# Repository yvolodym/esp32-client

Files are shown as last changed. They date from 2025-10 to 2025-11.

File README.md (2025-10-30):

```bash
idf.py set-target esp32-c3
idf.py build
idf.py -p /dev/ttyUSB0 flash monitor
```

ESP-NOW spezifisch:

CONFIG_ESPNOW_ENABLE=y - ESP-NOW aktiviert
CONFIG_ESPNOW_MAX_ENCRYPT_PEER_NUM=6 - Max. verschlüsselte Peers

Wichtige ESP32-C3 spezifische Einstellungen:

Ändere die server_mac Variable mit der MAC-Adresse deines Servers
Beide Geräte müssen auf Kanal 1 sein (oder ändere ESPNOW_WIFI_CHANNEL)

Single-Core (UNICORE) - C3 hat nur einen Core
RISC-V Architektur
Optimierte IRAM-Nutzung für WiFi
WPA3 Support aktiviert

Die Konfiguration ist optimiert für:

Niedrigen Stromverbrauch
Gute WiFi-Performance
ESP-NOW Kommunikation

### PINs
```
Motor Output 1: GPIO2
Motor Output 2: GPIO3
Input 1:        GPIO4
Input 2:        GPIO5
Sleep/Enable:   GPIO6
```

### URL
* https://github.com/EzerLonginus/CH340E_USB_UART
* https://community.element14.com/technologies/open-source-hardware/b/blog/posts/ch340-building-yet-another-usb-c-to-uart-adapter-board
* https://github.com/SolderedElectronics/USB-UART-CH340C-converter-board-hardware-design
* https://hci.rwth-aachen.de/lipo

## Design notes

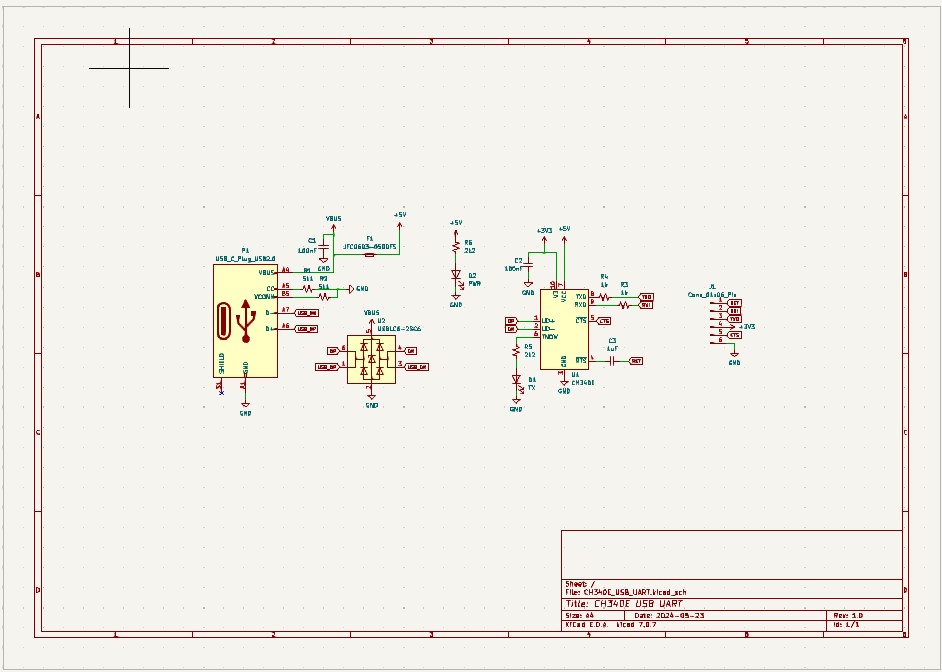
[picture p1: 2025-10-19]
doc/CH340E_schematic.jpeg

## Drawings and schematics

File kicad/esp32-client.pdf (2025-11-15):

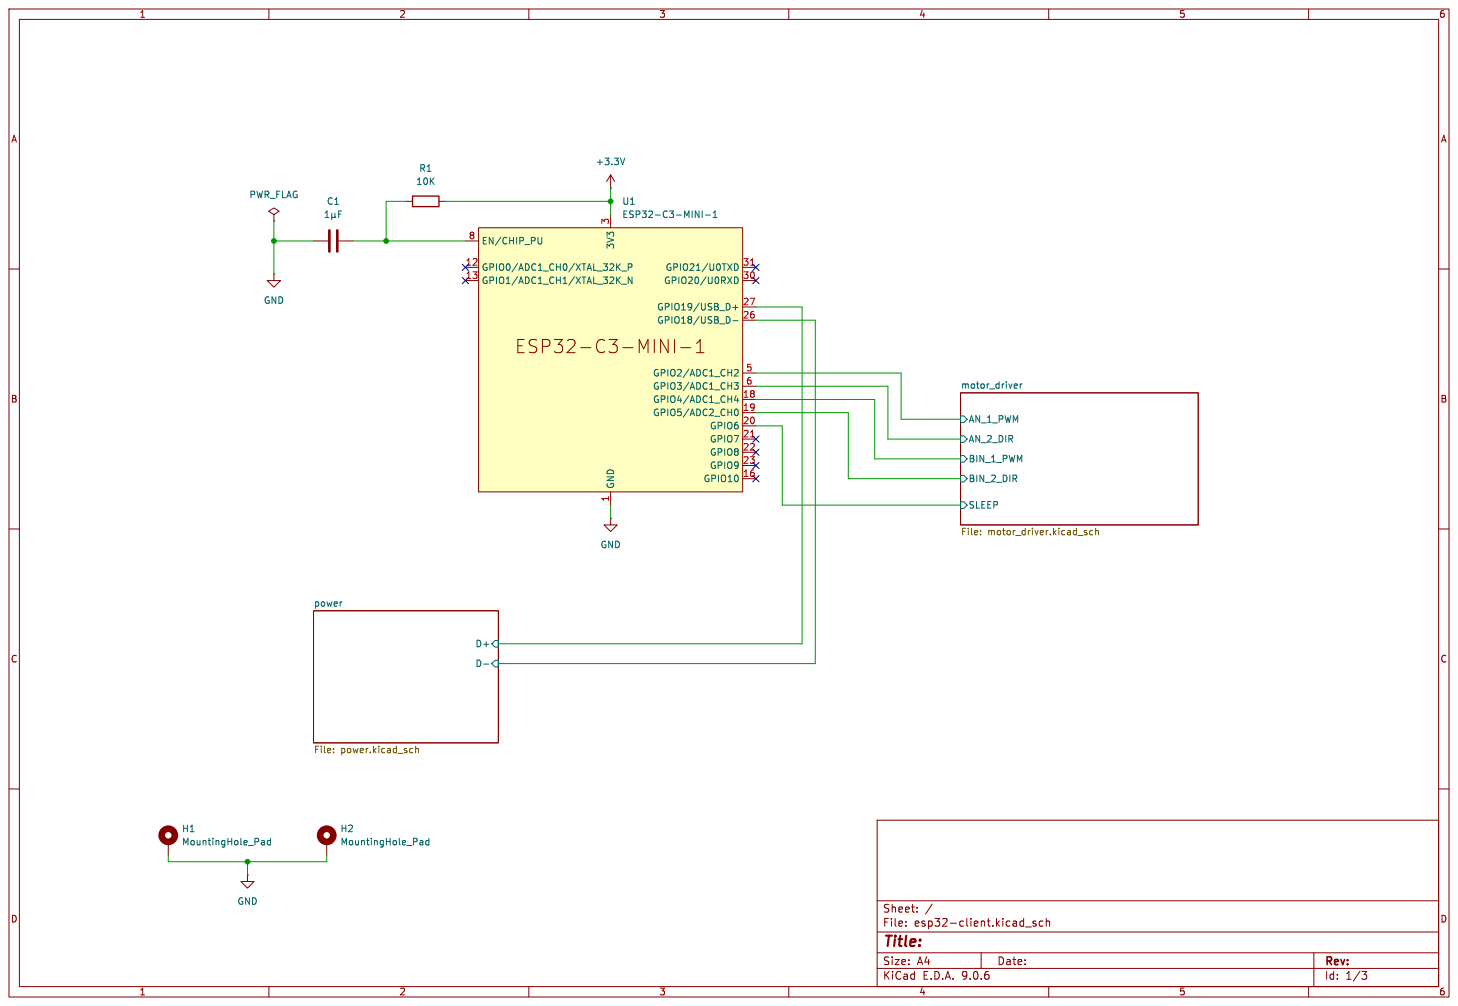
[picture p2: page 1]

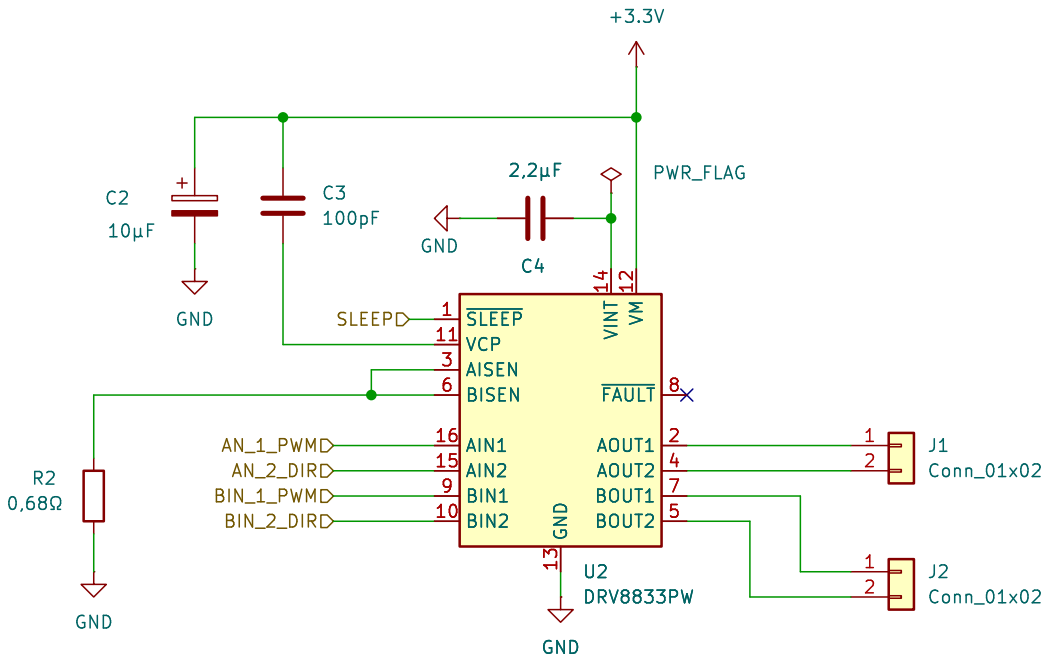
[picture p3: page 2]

Id: 2/3 Title: File: motor_driver.kicad_sch Sheet: /motor_driver/ R2

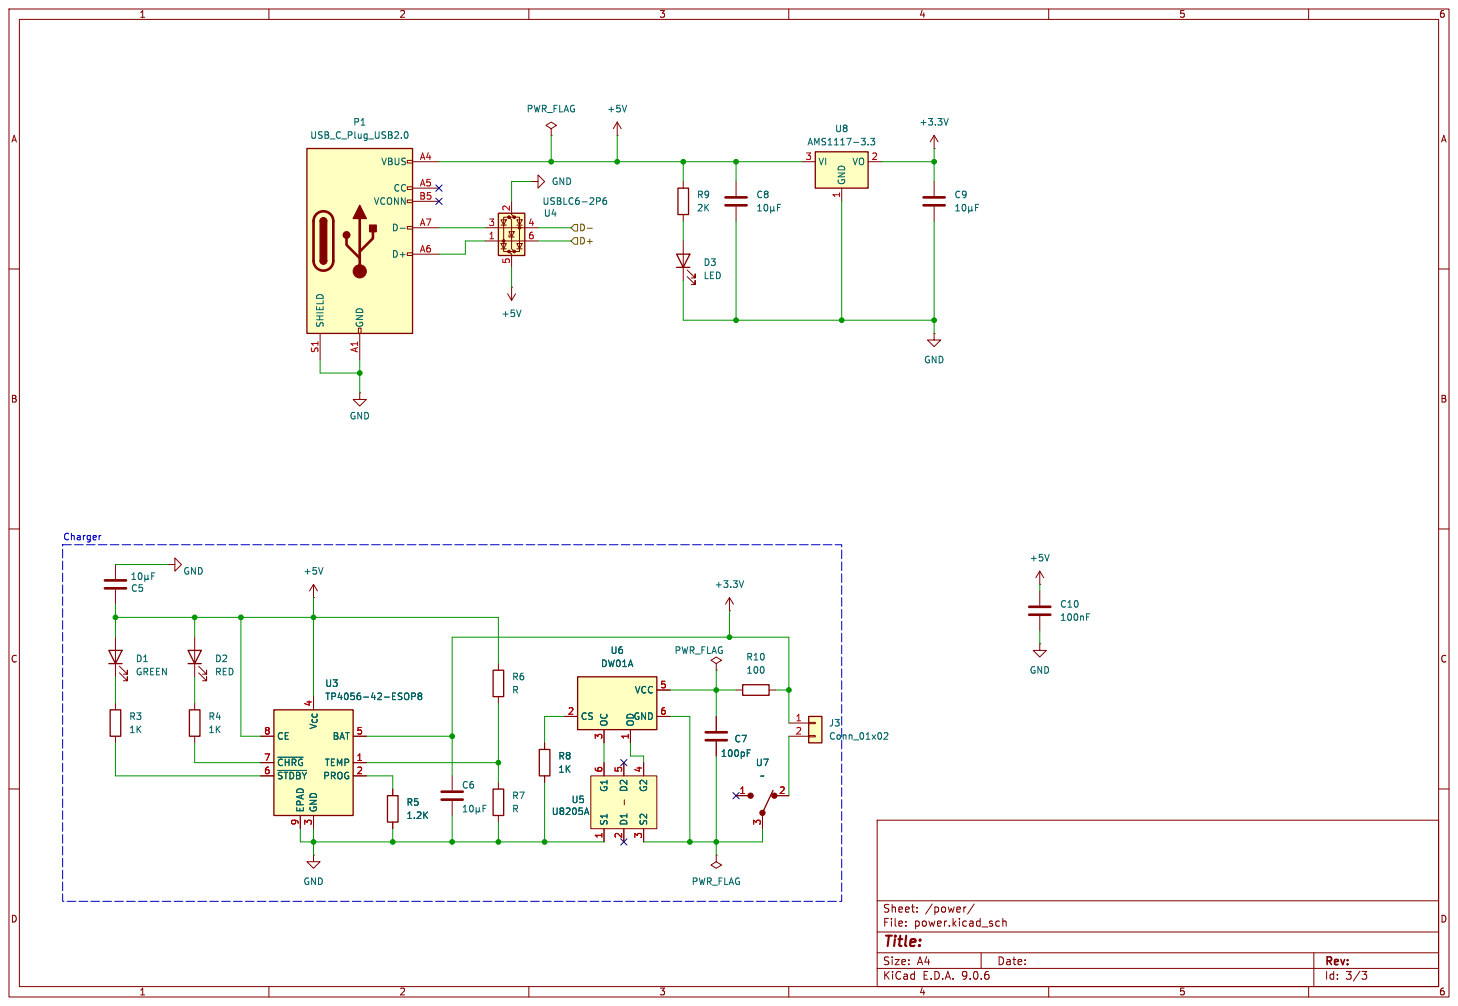
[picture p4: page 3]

3 BAT 5 TEMP 1 PROG 2 U3 TP4056-42-ESOP8 +5V GND

Id: 3/3 Title: File: power.kicad_sch Sheet: /power/ PWR_FLAG

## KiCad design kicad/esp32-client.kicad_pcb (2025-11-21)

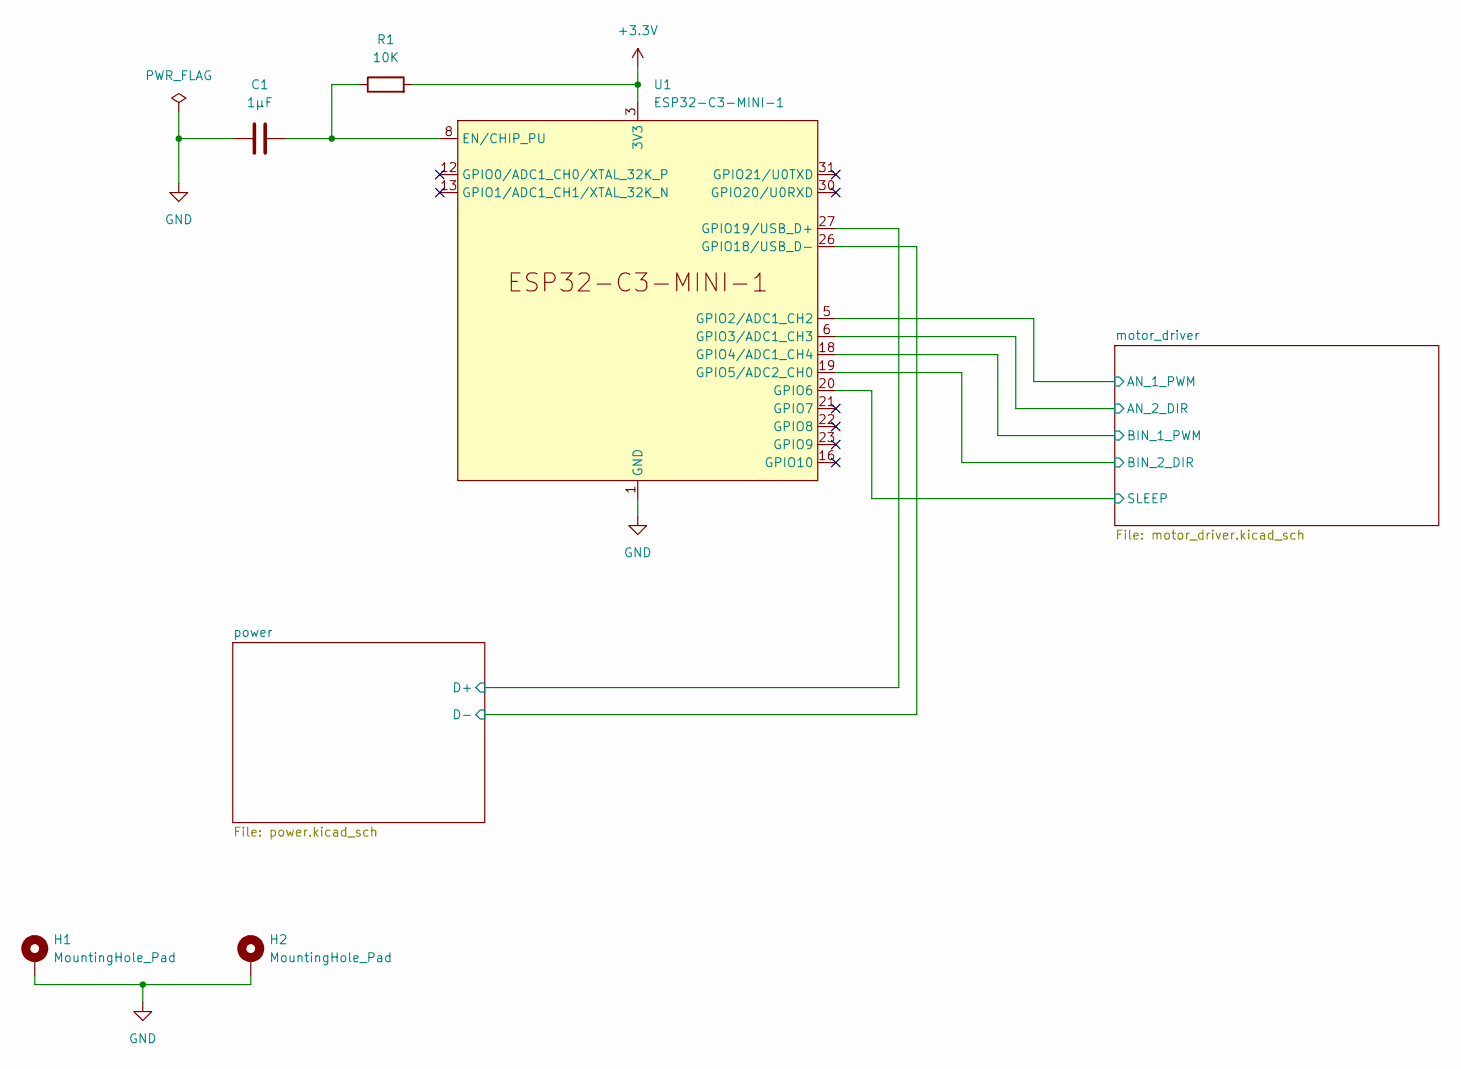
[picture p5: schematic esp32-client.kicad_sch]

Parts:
C1: 1µF; C_1206_3216Metric
H1, H2: MountingHole_Pad; MountingHole_2.5mm
R1: 10K; R_1206_3216Metric
U1: ESP32-C3-MINI-1

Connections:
+3.3V: R1.2, U1.3 (3V3); also elsewhere on the board
/motor_driver/AN_1_PWM: U1.5 (GPIO2/ADC1_CH2); also elsewhere on the board
/motor_driver/AN_2_DIR: U1.6 (GPIO3/ADC1_CH3); also elsewhere on the board
/motor_driver/BIN_1_PWM: U1.18 (GPIO4/ADC1_CH4); also elsewhere on the board
/motor_driver/BIN_2_DIR: U1.19 (GPIO5/ADC2_CH0); also elsewhere on the board
/motor_driver/SLEEP: U1.20 (GPIO6); also elsewhere on the board
/power/D+: U1.27 (GPIO19/USB_D+); also elsewhere on the board
/power/D-: U1.26 (GPIO18/USB_D-); also elsewhere on the board
GND: C1.2, H1.1, H2.1, U1.1 (GND), U1.2 (GND), U1.11 (GND), U1.14 (GND), U1.36 (GND), U1.37 (GND), U1.38 (GND), U1.39 (GND), U1.40 (GND), U1.41 (GND), U1.42 (GND), U1.43 (GND), U1.44 (GND), U1.45 (GND), U1.46 (GND), U1.47 (GND), U1.48 (GND), U1.49 (GND), U1.50 (GND), U1.51 (GND), U1.52 (GND), U1.53 (GND); also elsewhere on the board
unnamed: C1.1, R1.1, U1.8 (EN/CHIP_PU)

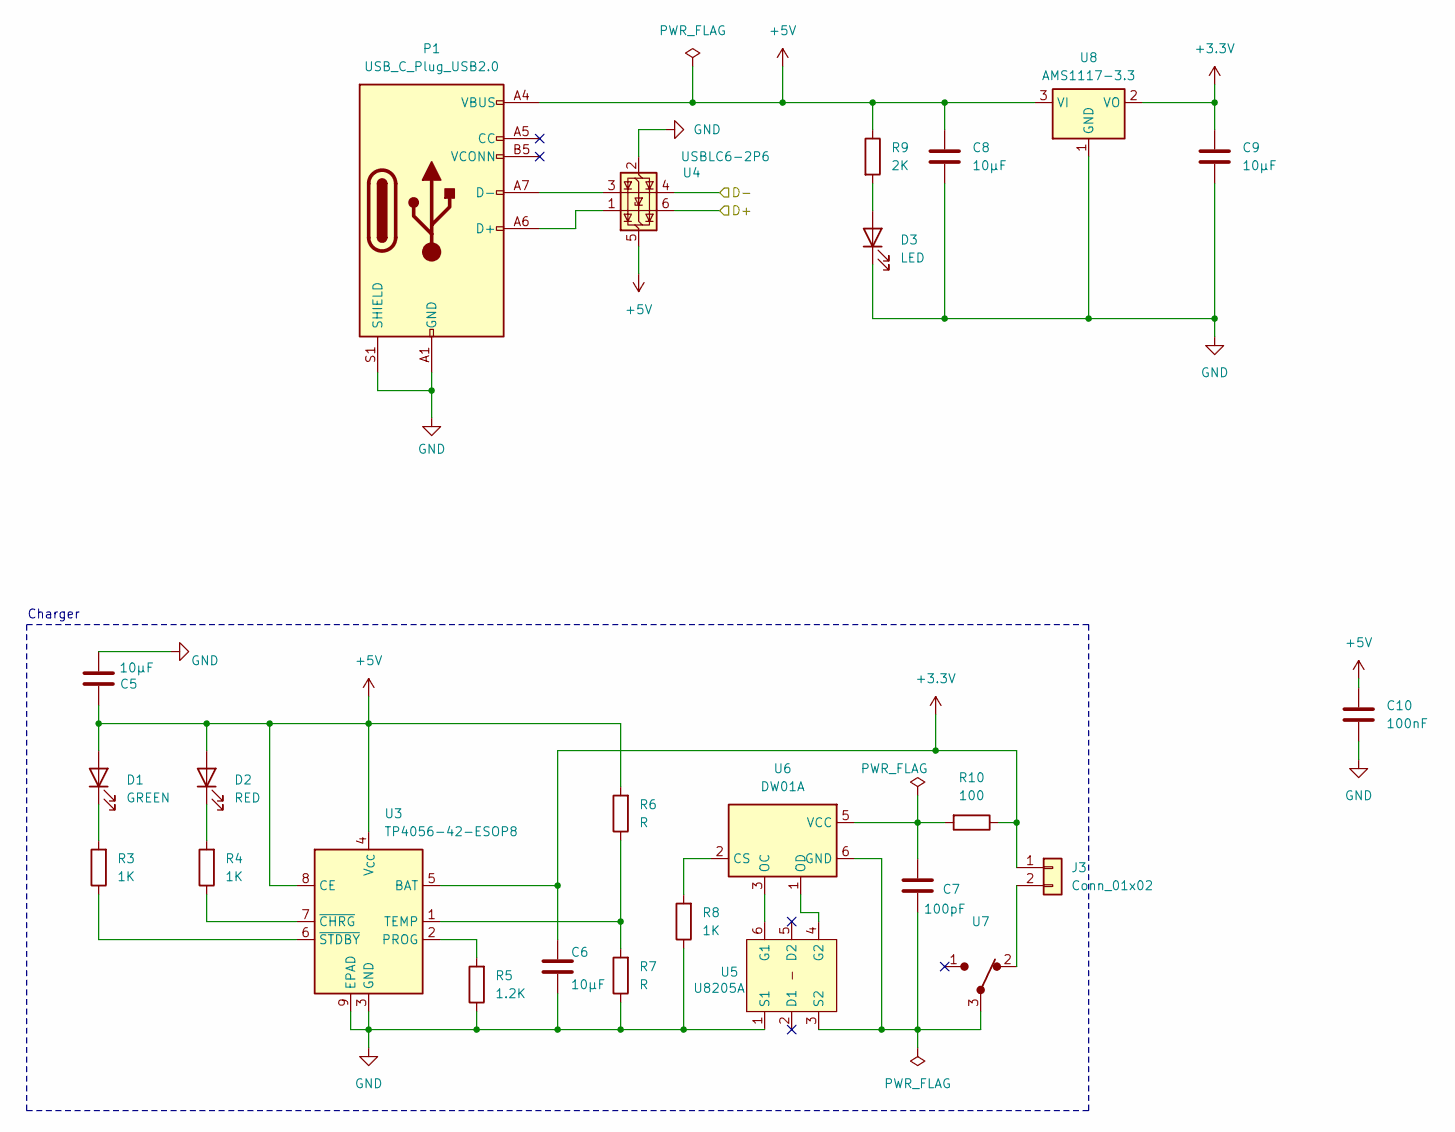
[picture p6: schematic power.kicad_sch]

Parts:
C5, C6, C8, C9: 10µF; C_1206_3216Metric
C7: 100pF; C_1206_3216Metric
C10: 100nF; C_1206_3216Metric
D1: GREEN; D_0603_1608Metric
D2: RED; D_0603_1608Metric
D3: LED; D_0603_1608Metric
J3: Conn_01x02; JST_PH_B2B-PH-K_1x02_P2.00mm_Vertical
P1: USB_C_Plug_USB2.0; USB_C_Receptacle_GCT_USB4105-xx-A_16P_TopMnt_Horizontal; LCSC C456012
R3, R4, R8: 1K; R_1206_3216Metric
R5: 1.2K; R_1206_3216Metric
R6, R7: R; R_1206_3216Metric
R9: 2K; R_1206_3216Metric
R10: 100; R_1206_3216Metric
U3: TP4056-42-ESOP8; SOIC-8-1EP_3.9x4.9mm_P1.27mm_EP2.41x3.3mm_ThermalVias
U4: USBLC6-2P6; SOT-23-6
U5: U8205A; SOT-23-6
U6: DW01A; SOT-23-6
U7: Switch
U8: AMS1117-3.3; SOT-223-3_TabPin2

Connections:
+3.3V: C6.1, C9.1, J3.1, R10.1, U3.5 (BAT), U8.2 (VO); also elsewhere on the board
+5V: C5.1, C8.1, C10.2, D1.2 (A), D2.2 (A), P1.A4 (VBUS), P1.A9 (VBUS), P1.B4 (VBUS), P1.B9 (VBUS), R6.2, R9.1, U3.4 (V_{CC}), U3.8 (CE), U4.5 (VBUS), U8.3 (VI)
/power/D+: U4.6 (I/O1); also elsewhere on the board
/power/D-: U4.4 (I/O2); also elsewhere on the board
GND: C5.2, C6.2, C8.2, C9.2, C10.1, D3.1 (K), P1.A1 (GND), P1.A12 (GND), P1.B1 (GND), P1.B12 (GND), P1.S1 (SHIELD), R5.1, R7.1, R8.1, U3.3 (GND), U3.9 (EPAD), U4.2 (GND), U5.1 (S1), U8.1 (GND); also elsewhere on the board
unnamed: D1.1 (K), R3.2
unnamed: D2.1 (K), R4.2
unnamed: D3.2 (A), R9.2
unnamed: J3.2, U7.2
unnamed: P1.A6 (D+), U4.1 (I/O1)
unnamed: P1.A7 (D-), U4.3 (I/O2)
unnamed: R5.2, U3.2 (PROG)
unnamed: R6.1, R7.2, U3.1 (TEMP)
unnamed: R4.1, U3.7 (~CHRG)
unnamed: R3.1, U3.6 (~STDBY)
unnamed: U5.6 (G1), U6.3 (OC)
unnamed: U5.4 (G2), U6.1 (OD)
unnamed: C7.1, U5.3 (S2), U6.6 (GND), U7.3
unnamed: R8.2, U6.2 (CS)
unnamed: C7.2, R10.2, U6.5 (VCC)

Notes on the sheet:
Charger

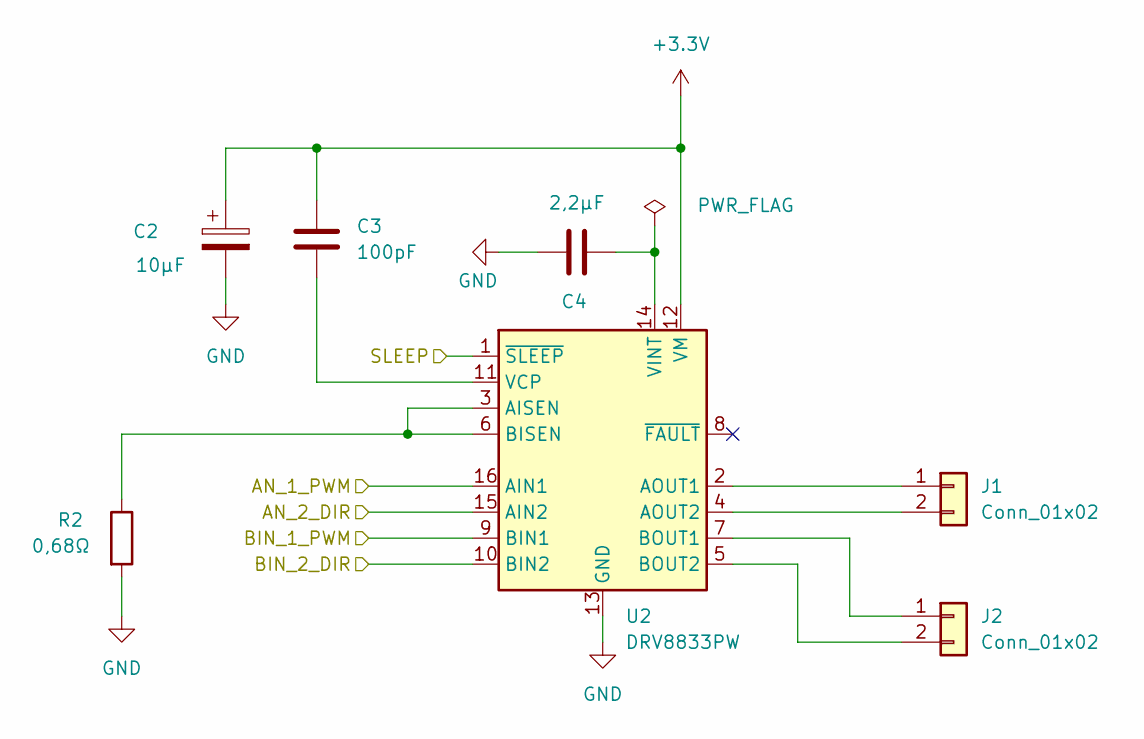
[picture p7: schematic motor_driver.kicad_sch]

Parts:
C2: 10µF; CP_Elec_4x3.9
C3: 100pF; C_1206_3216Metric
C4: 2,2µF; C_1206_3216Metric
J1, J2: Conn_01x02; JST_EH_B2B-EH-A_1x02_P2.50mm_Vertical
R2: 0,68Ω; R_1206_3216Metric
U2: DRV8833PW; TSSOP-16_4.4x5mm_P0.65mm

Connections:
+3.3V: C2.1, C3.1, U2.12 (VM); also elsewhere on the board
/motor_driver/AN_1_PWM: U2.16 (AIN1); also elsewhere on the board
/motor_driver/AN_2_DIR: U2.15 (AIN2); also elsewhere on the board
/motor_driver/BIN_1_PWM: U2.9 (BIN1); also elsewhere on the board
/motor_driver/BIN_2_DIR: U2.10 (BIN2); also elsewhere on the board
/motor_driver/SLEEP: U2.1 (~SLEEP); also elsewhere on the board
GND: C2.2, C4.1, R2.2, U2.13 (GND); also elsewhere on the board
unnamed: J1.1, U2.2 (AOUT1)
unnamed: J1.2, U2.4 (AOUT2)
unnamed: J2.1, U2.7 (BOUT1)
unnamed: J2.2, U2.5 (BOUT2)
unnamed: R2.1, U2.3 (AISEN), U2.6 (BISEN)
unnamed: C3.2, U2.11 (VCP)
unnamed: C4.2, U2.14 (VINT)

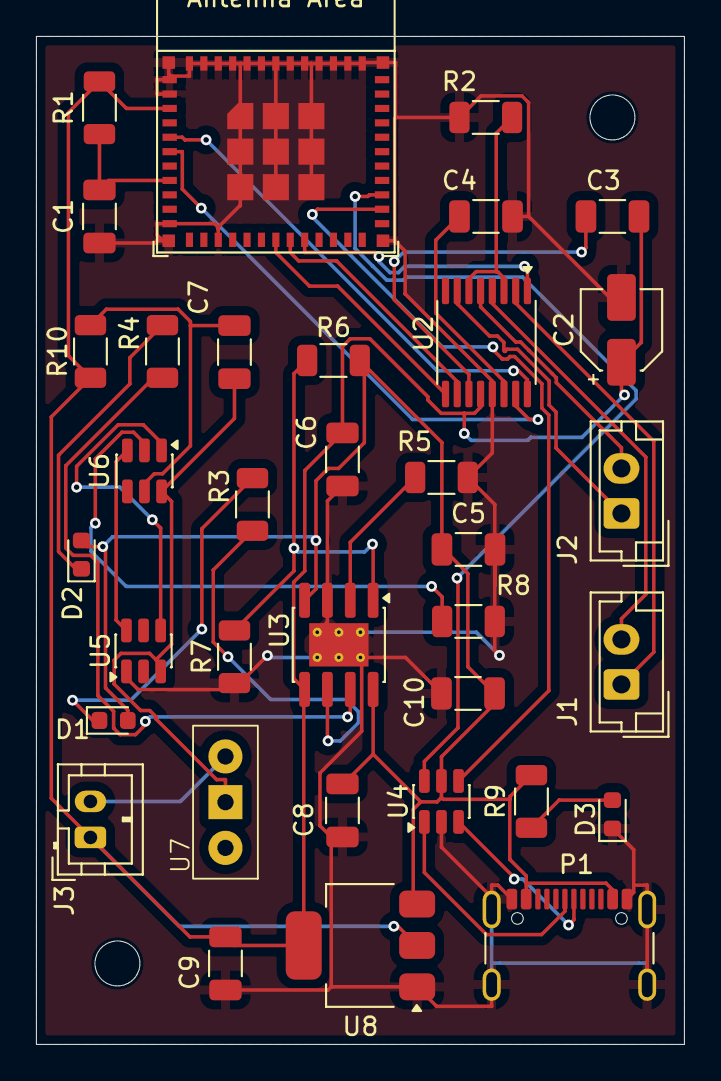
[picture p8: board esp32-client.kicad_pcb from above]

Board: 2 copper layers, 36.0 x 56.0 mm, 37 parts (0 on the bottom side), 33 nets.

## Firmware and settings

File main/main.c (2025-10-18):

#include <stdio.h>
#include <string.h>
#include <stdlib.h>
#include "freertos/FreeRTOS.h"
#include "freertos/task.h"
#include "esp_system.h"
#include "esp_wifi.h"
#include "esp_event.h"
#include "esp_log.h"
#include "esp_mac.h"
#include "nvs_flash.h"
#include "esp_now.h"

#define ESPNOW_WIFI_MODE WIFI_MODE_STA
#define ESPNOW_WIFI_CHANNEL 1

static const char *TAG = "ESPNOW_CLIENT";

// MAC-Adresse des Servers (anpassen!)
static uint8_t server_mac[6] = {0xFF, 0xFF, 0xFF, 0xFF, 0xFF, 0xFF};

// Callback für gesendete Daten
static void espnow_send_cb(const uint8_t *mac_addr, esp_now_send_status_t status)
{
    if (status == ESP_NOW_SEND_SUCCESS) {
        ESP_LOGI(TAG, "Daten erfolgreich gesendet");
    } else {
        ESP_LOGW(TAG, "Fehler beim Senden, Status: %d", status);
    }
}

// Callback für empfangene Daten
static void espnow_recv_cb(const esp_now_recv_info_t *recv_info, const uint8_t *data, int len)
{
    ESP_LOGI(TAG, "Daten empfangen von: %02X:%02X:%02X:%02X:%02X:%02X",
             recv_info->src_addr[0], recv_info->src_addr[1], recv_info->src_addr[2],
             recv_info->src_addr[3], recv_info->src_addr[4], recv_info->src_addr[5]);
    
    ESP_LOGI(TAG, "Daten: %.*s", len, data);
    ESP_LOGI(TAG, "RSSI: %d dBm", recv_info->rx_ctrl->rssi);
}

// WiFi Initialisierung
static void wifi_init(void)
{
    ESP_ERROR_CHECK(esp_netif_init());
    ESP_ERROR_CHECK(esp_event_loop_create_default());
    
    wifi_init_config_t cfg = WIFI_INIT_CONFIG_DEFAULT();
    ESP_ERROR_CHECK(esp_wifi_init(&cfg));
    ESP_ERROR_CHECK(esp_wifi_set_storage(WIFI_STORAGE_RAM));
    ESP_ERROR_CHECK(esp_wifi_set_mode(ESPNOW_WIFI_MODE));
    ESP_ERROR_CHECK(esp_wifi_start());
    ESP_ERROR_CHECK(esp_wifi_set_channel(ESPNOW_WIFI_CHANNEL, WIFI_SECOND_CHAN_NONE));
    
    // Long Range Mode für bessere Reichweite (optional)
    ESP_ERROR_CHECK(esp_wifi_set_protocol(ESP_IF_WIFI_STA, WIFI_PROTOCOL_11B|WIFI_PROTOCOL_11G|WIFI_PROTOCOL_11N|WIFI_PROTOCOL_LR));
    
    ESP_LOGI(TAG, "WiFi initialisiert, Kanal: %d", ESPNOW_WIFI_CHANNEL);
}

// ESP-NOW Initialisierung
static esp_err_t espnow_init(void)
{
    esp_err_t ret;
    
    ret = esp_now_init();
    if (ret != ESP_OK) {
        ESP_LOGE(TAG, "ESP-NOW Init fehlgeschlagen: %s", esp_err_to_name(ret));
        return ret;
    }
    
    // Callbacks registrieren
    ESP_ERROR_CHECK(esp_now_register_send_cb(espnow_send_cb));
    ESP_ERROR_CHECK(esp_now_register_recv_cb(espnow_recv_cb));
    
    // Peer (Server) hinzufügen
    esp_now_peer_info_t peer;
    memset(&peer, 0, sizeof(esp_now_peer_info_t));
    peer.channel = ESPNOW_WIFI_CHANNEL;
    peer.ifidx = ESP_IF_WIFI_STA;
    peer.encrypt = false;
    memcpy(peer.peer_addr, server_mac, 6);
    
    ret = esp_now_add_peer(&peer);
    if (ret != ESP_OK) {
        ESP_LOGE(TAG, "Peer hinzufügen fehlgeschlagen: %s", esp_err_to_name(ret));
        return ret;
    }
    
    ESP_LOGI(TAG, "ESP-NOW initialisiert");
    return ESP_OK;
}

// Task zum periodischen Senden von Daten
static void espnow_send_task(void *pvParameter)
{
    char data[250];
    uint32_t counter = 0;
    
    while (1) {
        snprintf(data, sizeof(data), "ESP32-C3 Client Nachricht #%lu", counter++);
        
        esp_err_t ret = esp_now_send(server_mac, (uint8_t *)data, strlen(data));
        if (ret != ESP_OK) {
            ESP_LOGE(TAG, "Senden fehlgeschlagen: %s", esp_err_to_name(ret));
        } else {
            ESP_LOGI(TAG, "Nachricht #%lu gesendet", counter - 1);
        }
        
        vTaskDelay(pdMS_TO_TICKS(5000)); // Alle 5 Sekunden senden
    }
}

void app_main(void)
{
    // NVS initialisieren
    esp_err_t ret = nvs_flash_init();
    if (ret == ESP_ERR_NVS_NO_FREE_PAGES || ret == ESP_ERR_NVS_NEW_VERSION_FOUND) {
        ESP_ERROR_CHECK(nvs_flash_erase());
        ret = nvs_flash_init();
    }
    ESP_ERROR_CHECK(ret);
    
    // Eigene MAC-Adresse ausgeben
    uint8_t mac[6];
    ESP_ERROR_CHECK(esp_read_mac(mac, ESP_MAC_WIFI_STA));
    ESP_LOGI(TAG, "===========================================");
    ESP_LOGI(TAG, "ESP32-C3 ESP-NOW Client");
    ESP_LOGI(TAG, "Client MAC: %02X:%02X:%02X:%02X:%02X:%02X",
             mac[0], mac[1], mac[2], mac[3], mac[4], mac[5]);
    ESP_LOGI(TAG, "===========================================");
    
    // WiFi und ESP-NOW initialisieren
    wifi_init();
    
    if (espnow_init() == ESP_OK) {
        // Task zum Senden starten
        xTaskCreate(espnow_send_task, "espnow_send_task", 4096, NULL, 5, NULL);
        ESP_LOGI(TAG, "ESP-NOW Client erfolgreich gestartet");
    } else {
        ESP_LOGE(TAG, "ESP-NOW Initialisierung fehlgeschlagen!");
    }
}
